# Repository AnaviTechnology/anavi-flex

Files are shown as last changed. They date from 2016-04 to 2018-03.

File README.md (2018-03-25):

# ANAVI Flex Raspberry Pi HAT

ANAVI Flex is an open source hardware Raspberry Pi HAT (add-on board) for rapid prototyping of Internet of Things (IoT) powered by free and open source software. It features:

* IR transmitter (IR LED)
* IR receiver (IR photo sensor)
* Relay
* Piezoelectric speaker (buzzer)
* Button
* RGB LED
* Slot for modular 16x2 LCD character display
* Slots for up to 5 plug and play I2C sensors for temperature, barometric pressure, humidity and light
* UART (Universal asynchronous receiver/transmitter) pins for debugging

The project was brought to life through a [crowdfunding campaign in IndieGoGo](https://igg.me/at/Rzjuluvxe6Y/10833949). You can still order it at [Tindie](https://www.tindie.com/products/anavi/anavi-flex-raspberry-pi-hat-for-iot/).

# Story

ANAVI Flex started as a small hobby project by Leon Anavi in November 2015. Initially the project was using off the shelf components but soon after that Leon decided to create his own Raspberry Pi HAT for easy IoT prototyping.

Inspired by Olimex and Tsvetan Uzunov's presentations about open source hardware at FOSDEM and Hackaday Belgrade, Leon insisted on using the free and open source electronics design automation suite KiCAD for the PCB design. In April 2016, the software engineer Leon bought his first soldering iron from Olimex and started working on the first hardware prototypes.

Designing PCB requires a lot of hardware skills and experience so Leon needed help. It was not easy to find a suitable hardware engineer familiar with KiCAD. After making a lot of contacts and speaking to various engineers finally Leon found the right people. Thanks to the PCB manufacturing services of OSH Park the first PCB prototypes were ready at the end of June 2016.

As expected the first version was far from perfect. There were  a few bugs which were quickly fixed. The next hardware revision and a small-run batch was ready in August 2016. It featured a new buzzer, a new button and a potentiometer for controlling the light and contrast of the LCD display module. 

In September 2016, after a lot of hard work, the first version of the user's manual of ANAVI Flex was released with open source examples written in Python and the C programming language.

In October 2016 first prototypes of ANAVI Flex were shipped to developers and bloggers. Another hardware revision with minor improvements was made and a small quantity of ANAVI Flex Raspberry Pi HATs was released on sale and quickly went out of stock in Tindie.

On 1 November 2016 ANAVI Flex crowdfunding campaign was launched in IndieGoGo. In 2017 the project was renamed from RabbitMax to ANAVI. The crowdfunding campaing was successful and all perks were shipped on time. Now can still order ANAVI Flex HAT at [Tindie](https://www.tindie.com/products/anavi/anavi-flex-raspberry-pi-hat-for-iot/).

# License

The project is released under the [Creative Commons Attribution-ShareAlike 4.0 International (CC BY-SA 4.0)](https://creativecommons.org/licenses/by-sa/4.0/).

Note: This is a human-readable summary of (and not a substitute for) the [license](https://creativecommons.org/licenses/by-sa/4.0/legalcode).

You are free to:

Share — copy and redistribute the material in any medium or format Adapt — remix, transform, and build upon the material for any purpose, even commercially. The licensor cannot revoke these freedoms as long as you follow the license terms. Under the following terms:

Attribution — You must give appropriate credit, provide a link to the license, and indicate if changes were made. You may do so in any reasonable manner, but not in any way that suggests the licensor endorses you or your use. ShareAlike — If you remix, transform, or build upon the material, you must distribute your contributions under the same license as the original. No additional restrictions — You may not apply legal terms or technological measures that legally restrict others from doing anything the license permits. Notices:

You do not have to comply with the license for elements of the material in the public domain or where your use is permitted by an applicable exception or limitation. No warranties are given. The license may not give you all of the permissions necessary for your intended use. For example, other rights such as publicity, privacy, or moral rights may limit how you use the material.

You will have to provide a link to the original creator of the project http://www.anavi.technology on any documentation or website.

Credit can be attributed through a link to the creator website: http://www.anavi.technology

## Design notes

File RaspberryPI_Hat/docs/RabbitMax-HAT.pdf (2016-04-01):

RabbitMax 1
Modular IoT HAT for Raspberry Pi

### 1. Specifications:

1x Piezo buzzer
1x RGB LED
1x Relay
1x “Push to make” button
1x IR receiver
1x IR transmitter
1x CAT24C32 EEPROM
3x 4 female pin headers for attaching i2c sensors (the sensors are not part of the HAT)
1x 16 female pin headers for attaching 1602 (or 2004) LCD character display (the display is not part of the HAT)

### 2. Size:

65x56mm

### 3. Sketch (work in progress, so far without IR and relay):

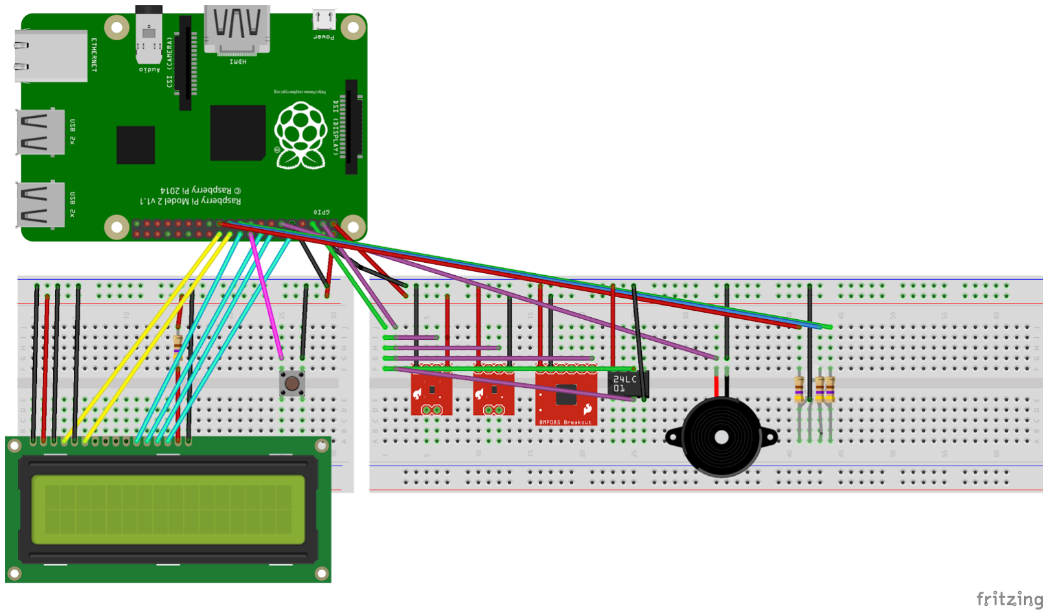
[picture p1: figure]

### 4. Sensors

Up to 3 of them will be attach as separate and pluggable modules to female pins for i2c on the HAT:
4.1. HTU21D temperature and humidity

4.2. TSL2561 light
4.3. BMP280 barometric pressure
4.4. BMP180 barometric pressure
4.5. HMC5883L digital compass

### 5. Resources:

https://www.raspberrypi.org/blog/introducingraspberrypihats/https://github.com/raspberrypi/hatshttps://www.raspberrypi.org/documentation/usage/gpioplusandraspi2/http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 (https://www.raspberrypi.org/magpi/make-your-own-hat/) http://openfet.com/2015/12/24/kicadhowtodesignaraspberrypihatin-10-minutes/ (http://openfet.com/2015/12/24/kicad-how-to-design-a-raspberry-pi-hat-in-10-minutes/) http://www.instructables.com/id/Designa-Raspberry-Pi-Hat-KiCad/ (http://www.instructables.com/id/Design-a-Raspberry-Pi-Hat-KiCad/) https://github.com/xesscorp/RPi_Hat_Templatehttps://forum.kicad.info/t/raspberrypibhattemplate/738/35 (https://forum.kicad.info/t/raspberry-pi-b-hat-template/738/35)

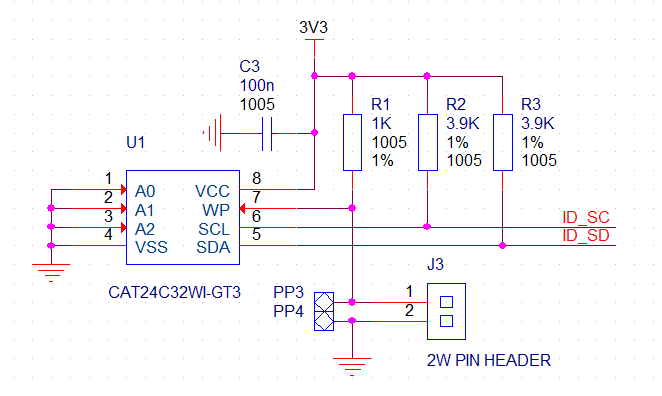
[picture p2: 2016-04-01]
RaspberryPI_Hat/docs/eeprom-circuit.png

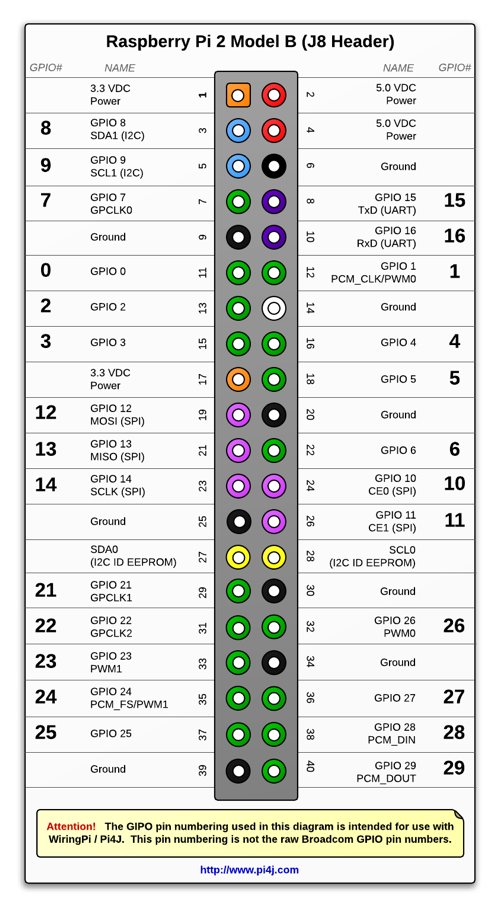
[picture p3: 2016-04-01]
RaspberryPI_Hat/docs/j8header-2b.png

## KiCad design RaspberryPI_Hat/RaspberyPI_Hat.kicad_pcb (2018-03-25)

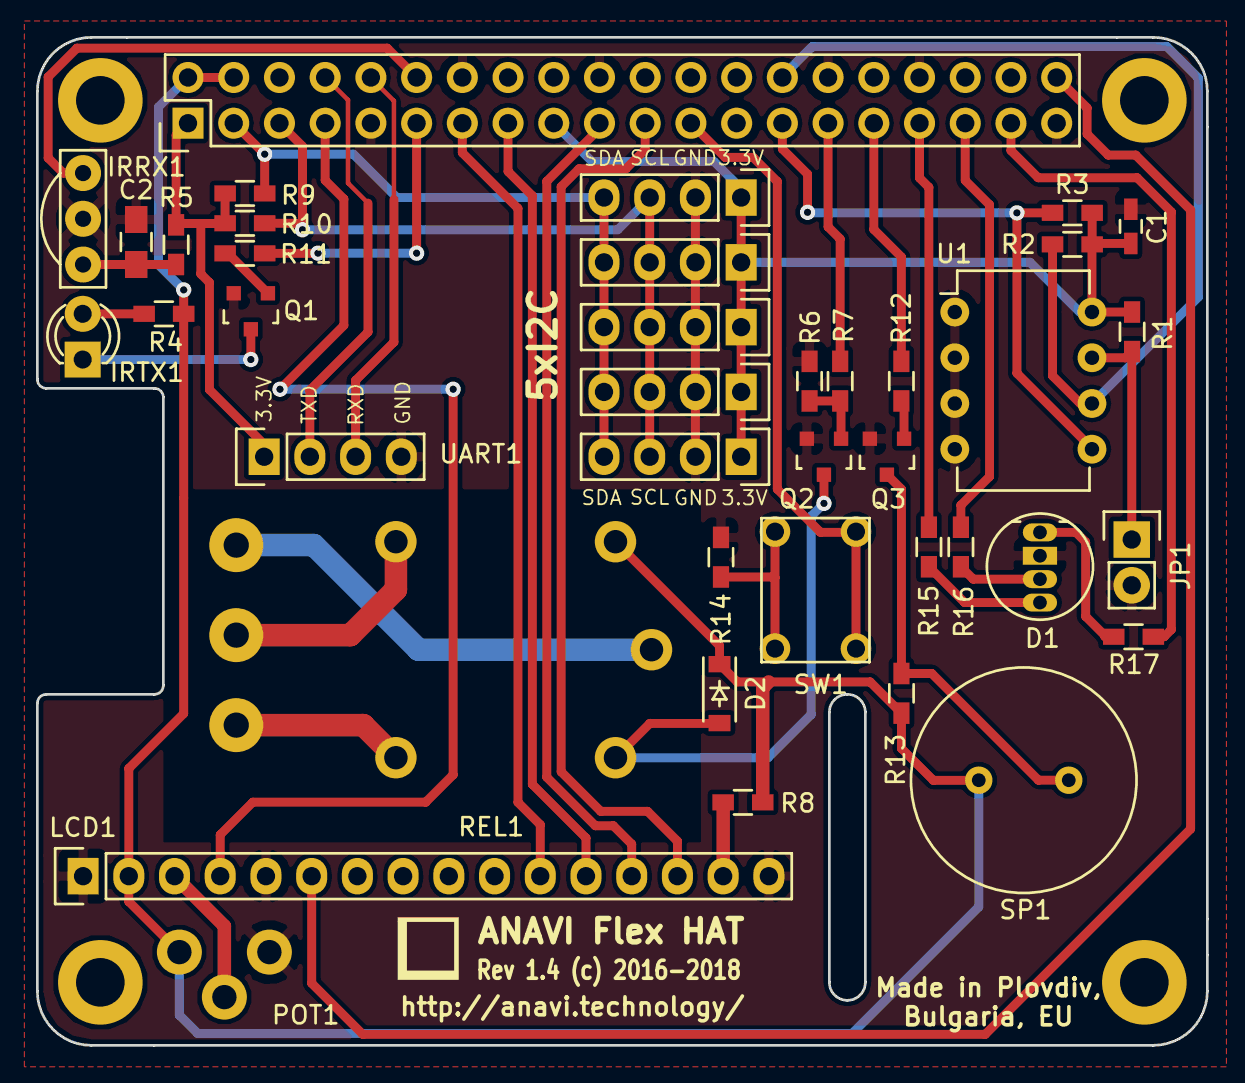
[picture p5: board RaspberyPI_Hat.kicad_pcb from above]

Board: 2 copper layers, 65.0 x 56.0 mm, 45 parts (0 on the bottom side), 41 nets.

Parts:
C1: 0.1; C_0603_HandSoldering
C2: 4.7; C_0805_HandSoldering
D1: LED_RCBG; LED-RGB-5MM_Common_Anode
D2: 1N4148; SOD-123
IRRX1: TSOP34838; TSOP38X
IRTX1: L-934F3BT; LED-3MM
JP1: JUMPER; Pin_Header_Straight_1x02
KL1: CONN_01X03; KLEMA_1x3
LCD1: LCD_16x2; Pin_Header_Straight_1x16
POT1: 10K; POT_VERT
Q1, Q2, Q3: BC817; SOT-23
R1, R13, R14: 1K; R_0603_HandSoldering
R2, R3, R9, R10: 4.7K; R_0603_HandSoldering
R4: 380; R_0603_HandSoldering
R5: 470; R_0603_HandSoldering
R6: 27K; R_0603_HandSoldering
R7: 2.7K; R_0603_HandSoldering
R8: 330; R_0603_HandSoldering
R11, R12: 10K; R_0603_HandSoldering
R15, R17: 60; R_0603_HandSoldering
R16: 300; R_0603_HandSoldering
RASP_CONN1: Raspberry_PI; Pin_Header_Straight_2x20
REF1, REF2, REF3, REF4: MountingHole_2.7mm_M2.5_DIN965_Pad
REL1: RAS-05-15
SENS1, SENS2, SENS3, SENS4, SENS5: I2C_SENS_1; Pin_Header_Straight_1x04
SP1: MCKPI-G1410-3668; MURATA_PKM13
SW1: SW_PUSH; TACT_SW_6
U1: CAT24C32WI-GT3; DIP-8_W7.62mm
UART1: CONN_01X04; Pin_Header_Straight_1x04

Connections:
+3V3: C1.1, R1.1, R2.1, R3.1, R5.1, R9.1, R10.1, RASP_CONN1.1, RASP_CONN1.17, SENS1.1, SENS2.1, SENS3.1, SENS4.1, SENS5.1, U1.8, UART1.1
+5V: D2.1, LCD1.2, POT1.1, R4.1, R8.2, R13.1, RASP_CONN1.2, RASP_CONN1.4, REL1.2, SP1.1
/D4: LCD1.11, RASP_CONN1.13
/D5: LCD1.12, RASP_CONN1.15
/D6: LCD1.13, RASP_CONN1.19
/D7: LCD1.14, RASP_CONN1.21
/EN: LCD1.6, RASP_CONN1.40
/LED1: R16.1, RASP_CONN1.35
/LED2: R15.1, RASP_CONN1.33
/LED3: R17.2, RASP_CONN1.37
/RS: LCD1.4, RASP_CONN1.7
/RXD: RASP_CONN1.10, UART1.3
/TXD: RASP_CONN1.8, UART1.2
GND: C1.2, C2.2, D1.2, IRRX1.2, JP1.2, LCD1.1, LCD1.5, LCD1.16, POT1.3, Q1.2, Q2.2, Q3.2, R6.1, R14.2, RASP_CONN1.6, RASP_CONN1.9, RASP_CONN1.14, RASP_CONN1.20, RASP_CONN1.25, RASP_CONN1.30, RASP_CONN1.34, RASP_CONN1.39, SENS1.2, SENS2.2, SENS3.2, SENS4.2, SENS5.2, U1.1, U1.2, U1.3, U1.4, UART1.4
unnamed: C2.1, IRRX1.3, R5.2
unnamed: D1.1, R17.1
unnamed: D1.3, R16.2
unnamed: D1.4, R15.2
unnamed: D2.2, Q2.3, REL1.4
unnamed: IRRX1.1, RASP_CONN1.12
unnamed: IRTX1.1, Q1.3
unnamed: IRTX1.2, R4.2
unnamed: JP1.1, R1.2, U1.7
unnamed: KL1.1, REL1.5
unnamed: KL1.2, REL1.1
unnamed: KL1.3, REL1.3
unnamed: LCD1.3, POT1.2
unnamed: LCD1.15, R8.1
unnamed: Q1.1, R11.1
unnamed: Q2.1, R6.2, R7.1
unnamed: Q3.1, R12.1
unnamed: Q3.3, R13.2, SP1.2
unnamed: R2.2, RASP_CONN1.28, U1.6
unnamed: R3.2, RASP_CONN1.27, U1.5
unnamed: R7.2, RASP_CONN1.29
unnamed: R9.2, RASP_CONN1.3, SENS1.4, SENS2.4, SENS3.4, SENS4.4, SENS5.4
unnamed: R10.2, RASP_CONN1.5, SENS1.3, SENS2.3, SENS3.3, SENS4.3, SENS5.3
unnamed: R11.2, RASP_CONN1.11
unnamed: R12.2, RASP_CONN1.31
unnamed: R14.1, SW1.1
unnamed: RASP_CONN1.23, SW1.2

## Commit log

2016-04-01 Първа версия с UEXT конектор
    [RaspberyPI_Hat.kicad_pcb, RaspberyPI_Hat.sch]
2016-04-01 Добавено реле
    [RaspberyPI_Hat.kicad_pcb, RaspberyPI_Hat.sch]
2016-04-01 Промяна на UEXT на 2x05 корпус
    [RaspberyPI_Hat.kicad_pcb, RaspberyPI_Hat.sch]
2016-04-01 Обърнат конектор 2x20
    [RaspberyPI_Hat.kicad_pcb]
2016-04-04 Добавено LCD
    [RaspberyPI_Hat.kicad_pcb, RaspberyPI_Hat.sch]
2016-04-11 Добавени хедъри за сензори, бутон, зумер
    [RaspberyPI_Hat.kicad_pcb, RaspberyPI_Hat.sch]
2016-04-12 Добавен RG LED оправени корпуси
    [RaspberyPI_Hat.kicad_pcb, RaspberyPI_Hat.sch]
2016-04-13 Започнато трасиране на платка
    [RaspberyPI_Hat.kicad_pcb, RaspberyPI_Hat.sch]
2016-04-15 Първи вариант PCB
    [RaspberyPI_Hat.kicad_pcb, RaspberyPI_Hat.sch]
2016-04-24 Рзместени IR и зумер, сменен RGB диод
    [RaspberyPI_Hat.kicad_pcb, RaspberyPI_Hat.sch]
2016-05-26 Last tweaks before first prototype run
    [RaspberyPI_Hat.kicad_pcb, RaspberyPI_Hat.sch]
2016-05-31 IR Diod moved to pin 11
    [RaspberyPI_Hat.kicad_pcb, RaspberyPI_Hat.sch]
2016-06-01 RS interface added
    [RaspberyPI_Hat.kicad_pcb, RaspberyPI_Hat.sch]
2016-06-03 Added logo
    [RaspberyPI_Hat.kicad_pcb]
2016-06-04 Text on socket's pads
    [RaspberyPI_Hat.kicad_pcb, RaspberyPI_Hat.sch]
2016-06-04 Changed to 5 I2C sensors on headers
    [RaspberyPI_Hat.kicad_pcb, RaspberyPI_Hat.sch]
2016-06-06 changed IRRT to pin 11 RS to pin 7
    [RaspberyPI_Hat.kicad_pcb, RaspberyPI_Hat.sch]
2016-06-06 changed common A to common Katode RGB LED
    [RaspberyPI_Hat.kicad_pcb, RaspberyPI_Hat.sch]
2016-06-06 Gerber and drill files added
    [RaspberyPI_Hat-B.Cu.gbl, RaspberyPI_Hat-B.Mask.gbs, RaspberyPI_Hat-B.SilkS.gbo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]
2016-06-29 BOM added
    [RaspberyPI_Hat.sch]
2016-08-03 Moved relay and terminal, changed zummer, added trimmer for contrast control of LCD, added Made in Bulgaria, chnaged button, changed value of button resistor
    [RaspberyPI_Hat.kicad_pcb, RaspberyPI_Hat.sch]
2016-08-03 Changed trimmer part
    [RaspberyPI_Hat.kicad_pcb]
2016-08-05 Change revision number
    Added separate footprint for rabbit logo
    [RaspberyPI_Hat.kicad_pcb]
2016-08-05 Add rev 1.1 plots
    [RaspberyPI_Hat-B.Cu.gbl, RaspberyPI_Hat-B.Mask.gbs, RaspberyPI_Hat-Edge.Cuts.gm1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]
2016-08-14 revision-1.0: Rename plots for v1.0
    Rename directory with plots according to the
    naming convension started by Rangel.
    [RaspberyPI_Hat-B.Cu.gbl, RaspberyPI_Hat-B.Mask.gbs, RaspberyPI_Hat-B.SilkS.gbo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]
2016-08-14 RaspberyPI_Hat.kicad_pcb: Move and update labels
    The following changes have been applied to the
    silk screen:
    - Hide labels K and KL1
    - Move IRTX1
    - Move REL1
    - Move SW1
    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
    [RaspberyPI_Hat.kicad_pcb]
2016-08-16 Changed drill sizes for button and buzzer
    [RaspberyPI_Hat.kicad_pcb, RaspberyPI_Hat.sch]
2016-09-15 Buton drill holes sizes, buzzer, moved POT1
    [RaspberyPI_Hat.kicad_pcb, RaspberyPI_Hat.sch]
2016-10-15 POT1 connected to PIN3 of LCD, added R8, for LCD backlight current limit.
    [RaspberyPI_Hat.kicad_pcb, RaspberyPI_Hat.sch]
2016-10-27 RaspberyPI_Hat.kicad_pcb: Set version to 1.3
    [RaspberyPI_Hat.kicad_pcb]
2016-11-05 RaspberyPI_Hat.kicad_pcb: rev 1.3
    Configure export options for revision 1.3
    [RaspberyPI_Hat.kicad_pcb]
2016-12-28 F.Fab: SMT footprint assembly
    Add information about SMT footprint assembly.
    [RaspberyPI_Hat.kicad_pcb]
2018-03-25 Update logo and change version to 1.4
    Change the logo and the text on the silkscreen.
    [RaspberyPI_Hat.kicad_pcb]
2018-03-25 README.md: CC BY-SA 4.0
    Switch license to CC BY-SA 4.0 because my newer
    open source hardware projects are with it.

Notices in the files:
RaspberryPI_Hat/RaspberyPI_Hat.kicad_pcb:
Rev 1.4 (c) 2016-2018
